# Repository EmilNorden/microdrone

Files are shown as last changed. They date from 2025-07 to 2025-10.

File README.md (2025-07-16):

# microdrone

## Controller dev kit

ESP32-S3-Wroom-1-n8r8\
Datasheet: https://www.espressif.com/sites/default/files/documentation/esp32-s3-wroom-1_wroom-1u_datasheet_en.pdf \
Hardware ref: https://docs.espressif.com/projects/esp-dev-kits/en/latest/esp32s3/esp32-s3-devkitc-1/user_guide_v1.1.html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 \
Power: 3.0-3.6V\
Rust dev on ESP32: https://docs.espressif.com/projects/rust/book/

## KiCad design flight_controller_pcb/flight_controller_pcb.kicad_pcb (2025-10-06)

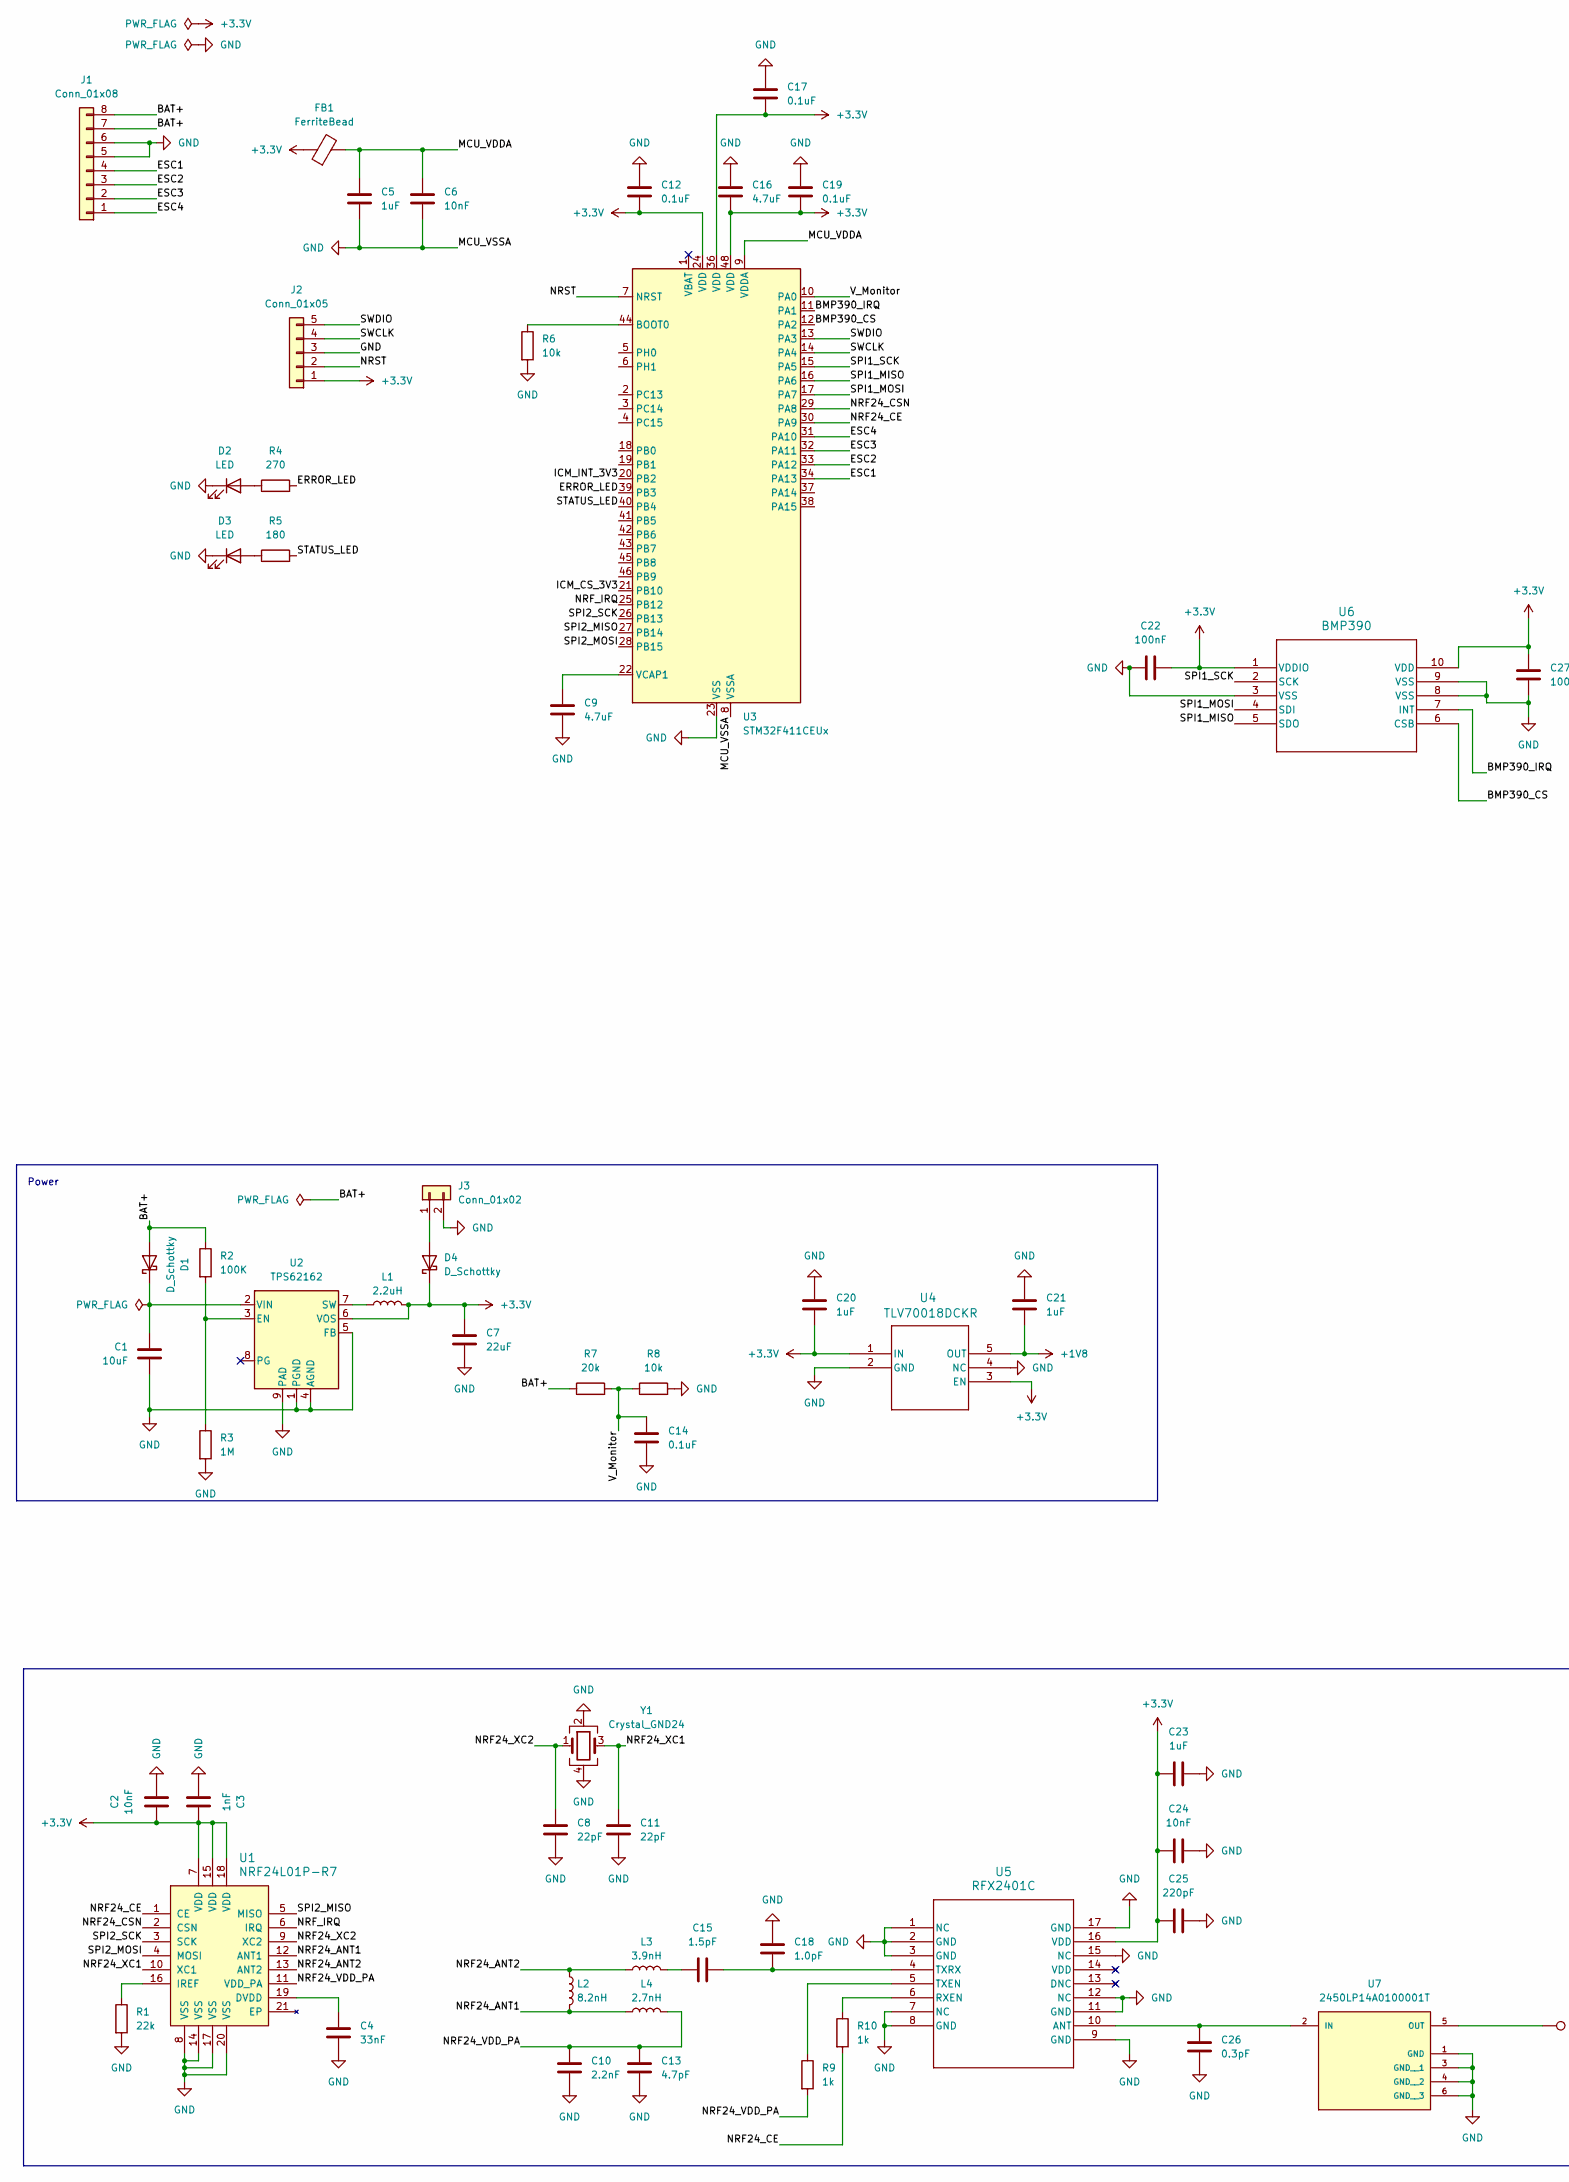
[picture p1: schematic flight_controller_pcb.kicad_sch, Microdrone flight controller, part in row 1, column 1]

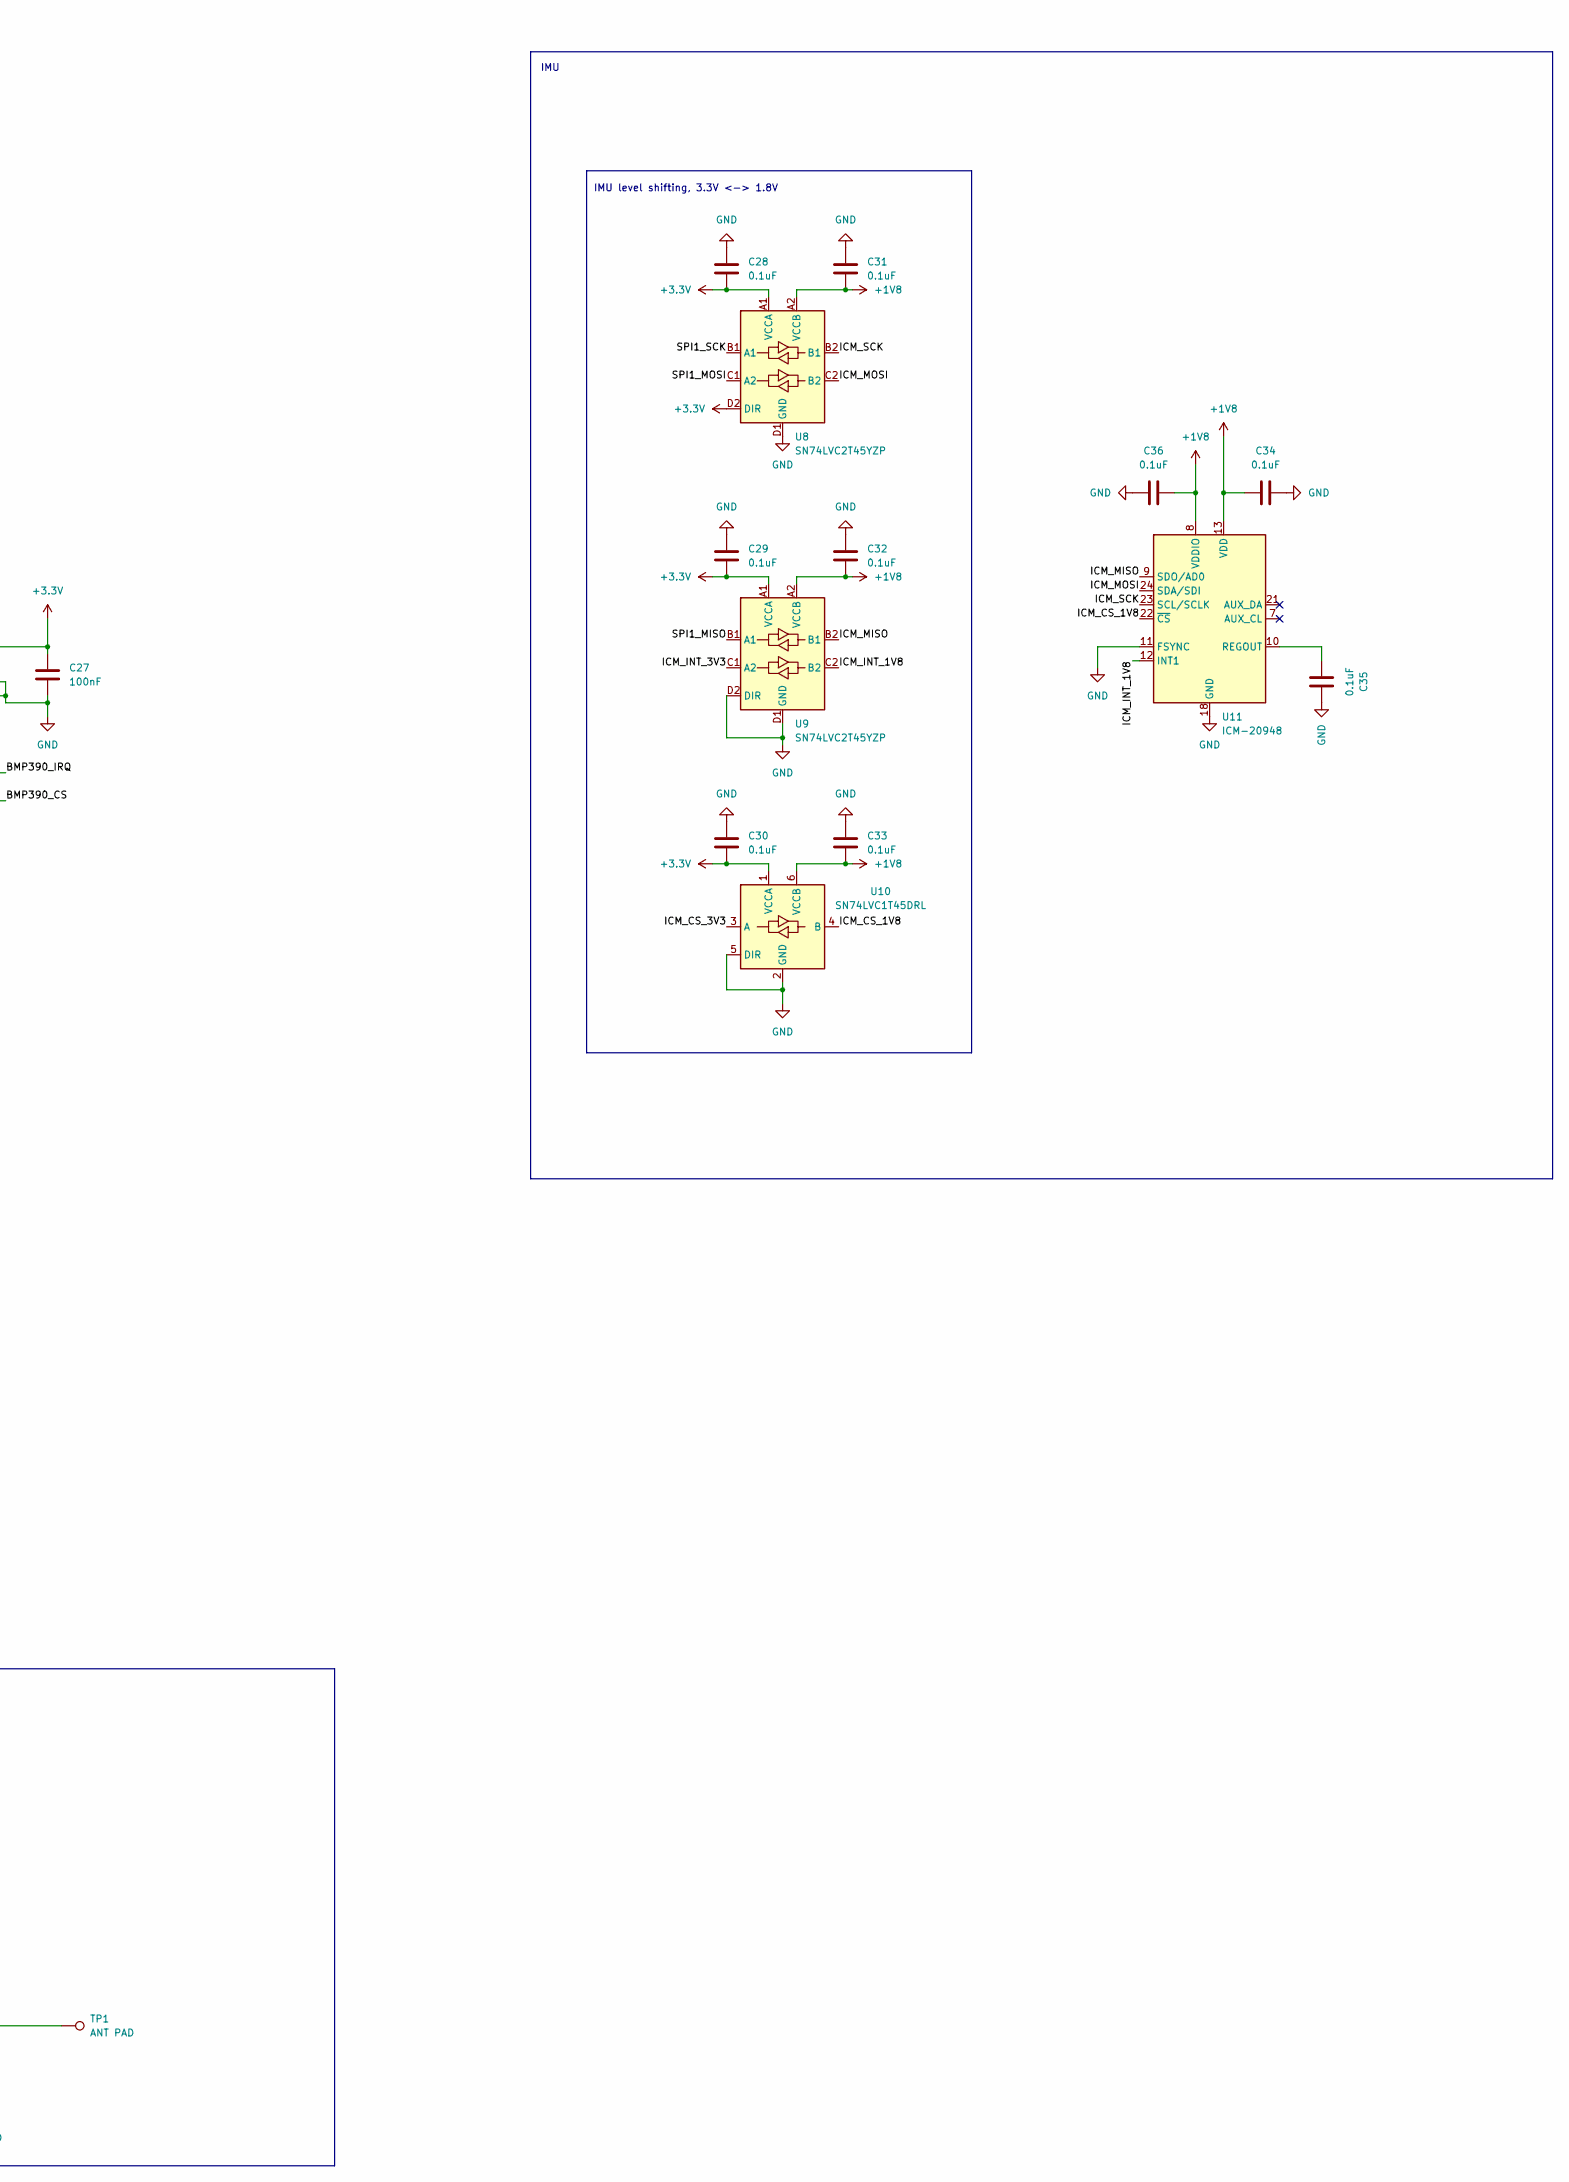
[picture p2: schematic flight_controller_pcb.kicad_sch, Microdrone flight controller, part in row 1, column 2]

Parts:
C1: 10uF; C_0603_1608Metric
C2, C6: 10nF; C_0402_1005Metric
C3: 1nF; C_0402_1005Metric
C4: 33nF; C_0402_1005Metric
C5, C20, C21, C23: 1uF; C_0402_1005Metric
C7: 22uF; C_0805_2012Metric
C8, C11: 22pF; C_0402_1005Metric
C9: 4.7uF; C_0603_1608Metric
C10: 2.2nF; C_0402_1005Metric
C12, C14, C17, C19, C28, C29, C30, C31, C32, C33: 0.1uF; C_0402_1005Metric
C13: 4.7pF; C_0402_1005Metric
C15: 1.5pF; C_0402_1005Metric
C16: 4.7uF; C_0603_1608Metric; LCSC C107368
C18: 1.0pF; C_0402_1005Metric
C22, C27: 100nF; C_0402_1005Metric
C24: 10nF; C_0603_1608Metric
C25: 220pF; C_0402_1005Metric
C26: 0.3pF; C_0201_0603Metric
C34, C35, C36: 0.1uF; C_0402_1005Metric; LCSC C1525
D1: D_Schottky; D_SOD-323
D2, D3: LED; LED_0402_1005Metric
D4: D_Schottky; Diode_SMD_SOD-723
FB1: FerriteBead; L_0603_1608Metric; LCSC C1002
J1: Conn_01x08; JST_SH_ZX-SH1.0-8PWT; LCSC C7430450
J2: Conn_01x05; PinHeader_1x05_P2.54mm_Horizontal
J3: Conn_01x02; PinHeader_1x02_P2.54mm_Horizontal
L1: 2.2uH; Inductor_Coilcraft_XFL3012-222MEC
L2: 8.2nH; L_0201_0603Metric
L3: 3.9nH; L_0201_0603Metric
L4: 2.7nH; L_0201_0603Metric
R1: 22k; R_0402_1005Metric
R2: 100K; R_0402_1005Metric
R3: 1M; R_0402_1005Metric
R4: 270; R_0402_1005Metric
R5: 180; R_0402_1005Metric
R6, R8: 10k; R_0402_1005Metric
R7: 20k; R_0402_1005Metric
R9, R10: 1k; R_0402_1005Metric
TP1: ANT PAD; TestPoint_Pad_3.0x3.0mm
U1: NRF24L01P-R7; QFN-20-1EP_4x4mm_RevA; MPN NRF24L01P-R7; Digi-Key_PN 1490-1033-1-ND
U2: TPS62162; WSON-8-1EP_2x2mm_P0.5mm_EP0.9x1.6mm_ThermalVias
U3: STM32F411CEUx; QFN-48-1EP_7x7mm_P0.5mm_EP5.6x5.6mm
U4: TLV70018DCKR; DCK5
U5: RFX2401C; RFX2401C_SKY
U6: BMP390; 10LGA_2X2X0p75_BOS
U7: 2450LP14A0100001T; ICCAF50P160X80X70-6N; PARTREV 06/23/03
U8, U9: SN74LVC2T45YZP; Texas_DSBGA-8_0.9x1.9mm_Layout2x4_P0.5mm
U10: SN74LVC1T45DRL; SOT-563
U11: ICM-20948; InvenSense_QFN-24_3x3mm_P0.4mm
Y1: Crystal_GND24; Crystal_SMD_3225-4Pin_3.2x2.5mm

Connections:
+1V8: C21.2, C31.2, C32.2, C33.2, C34.1, C36.2, U4.5 (OUT), U8.A2 (VCCB), U9.A2 (VCCB), U10.6 (VCCB), U11.8 (VDDIO), U11.13 (VDD)
+3.3V: C2.1, C3.1, C7.1, C12.1, C16.1, C17.1, C19.1, C20.2, C22.2, C23.1, C24.1, C25.1, C27.1, C28.2, C29.2, C30.2, D4.1 (K), FB1.1, J2.1, L1.2, U1.7 (VDD), U1.15 (VDD), U1.18 (VDD), U2.6 (VOS), U3.24 (VDD), U3.36 (VDD), U3.48 (VDD), U4.1 (IN), U4.3 (EN), U5.16 (VDD), U6.1 (VDDIO), U6.10 (VDD), U8.A1 (VCCA), U8.D2 (DIR), U9.A1 (VCCA), U10.1 (VCCA)
/BAT+: D1.2 (A), J1.7, J1.8, R2.1, R7.1
/BMP390_CS: U3.12 (PA2), U6.6 (CSB)
/BMP390_IRQ: U3.11 (PA1), U6.7 (INT)
/ERROR_LED: R4.2, U3.39 (PB3)
/ESC1: J1.4, U3.34 (PA13)
/ESC2: J1.3, U3.33 (PA12)
/ESC3: J1.2, U3.32 (PA11)
/ESC4: J1.1, U3.31 (PA10)
/ICM_CS_1V8: U10.4 (B), U11.22 (~CS)
/ICM_CS_3V3: U3.21 (PB10), U10.3 (A)
/ICM_INT_1V8: U9.C2 (B2), U11.12 (INT1)
/ICM_INT_3V3: U3.20 (PB2), U9.C1 (A2)
/ICM_MISO: U9.B2 (B1), U11.9 (SDO/AD0)
/ICM_MOSI: U8.C2 (B2), U11.24 (SDA/SDI)
/ICM_SCK: U8.B2 (B1), U11.23 (SCL/SCLK)
/MCU_VDDA: C5.1, C6.1, FB1.2, U3.9 (VDDA)
/NRF24_ANT1: L2.2, L4.1, U1.12 (ANT1)
/NRF24_ANT2: L2.1, L3.1, U1.13 (ANT2)
/NRF24_CE: R10.2, U1.1 (CE), U3.30 (PA9)
/NRF24_CSN: U1.2 (CSN), U3.29 (PA8)
/NRF24_VDD_PA: C10.1, C13.1, L4.2, R9.2, U1.11 (VDD_PA)
/NRF24_XC1: C11.1, U1.10 (XC1), Y1.3
/NRF24_XC2: C8.1, U1.9 (XC2), Y1.1
/NRF_IRQ: U1.6 (IRQ), U3.25 (PB12)
/NRST: J2.2, U3.7 (NRST)
/SPI1_MISO: U3.16 (PA6), U6.5 (SDO), U9.B1 (A1)
/SPI1_MOSI: U3.17 (PA7), U6.4 (SDI), U8.C1 (A2)
/SPI1_SCK: U3.15 (PA5), U6.2 (SCK), U8.B1 (A1)
/SPI2_MISO: U1.5 (MISO), U3.27 (PB14)
/SPI2_MOSI: U1.4 (MOSI), U3.28 (PB15)
/SPI2_SCK: U1.3 (SCK), U3.26 (PB13)
/STATUS_LED: R5.2, U3.40 (PB4)
/SWCLK: J2.4, U3.14 (PA4)
/SWDIO: J2.5, U3.13 (PA3)
/V_Monitor: C14.2, R7.2, R8.1, U3.10 (PA0)
GND: C1.2, C2.2, C3.2, C4.1, C5.2, C6.2, C7.2, C8.2, C9.1, C10.2, C11.2, C12.2, C13.2, C14.1, C16.2, C17.2, C18.1, C19.2, C20.1, C21.1, C22.1, C23.2, C24.2, C25.2, C26.2, C27.2, C28.1, C29.1, C30.1, C31.1, C32.1, C33.1, C34.2, C35.2, C36.1, D2.1 (K), D3.1 (K), J1.5, J1.6, J2.3, J3.2, R1.2, R3.2, R6.2, R8.2, U1.8 (VSS), U1.14 (VSS), U1.17 (VSS), U1.20 (VSS), U2.1 (PGND), U2.4 (AGND), U2.5 (FB), U2.9 (PAD), U3.8 (VSSA), U3.23 (VSS), U3.35 (VSS), U3.47 (VSS), U3.49 (VSS), U4.2 (GND), U4.4 (NC), U5.1 (NC), U5.2 (GND), U5.3 (GND), U5.7 (NC), U5.8 (GND), U5.9 (GND), U5.11 (GND), U5.12 (NC), U5.15 (NC), U5.17 (GND), U6.3 (VSS), U6.8 (VSS), U6.9 (VSS), U7.1 (GND), U7.3 (GND__1), U7.4 (GND__2), U7.6 (GND__3), U8.D1 (GND), U9.D1 (GND), U9.D2 (DIR), U10.2 (GND), U10.5 (DIR), U11.11 (FSYNC), U11.18 (GND), U11.20 (GND), Y1.2, Y1.4
unnamed: C15.1, L3.2
unnamed: C1.1, D1.1 (K), U2.2 (VIN)
unnamed: D2.2 (A), R4.1
unnamed: D3.2 (A), R5.1
unnamed: D4.2 (A), J3.1
unnamed: C4.2, U1.19 (DVDD)
unnamed: R1.1, U1.16 (IREF)
unnamed: R2.2, R3.1, U2.3 (EN)
unnamed: L1.1, U2.7 (SW)
unnamed: R6.1, U3.44 (BOOT0)
unnamed: C9.2, U3.22 (VCAP1)
unnamed: C26.1, U5.10 (ANT), U7.2 (IN)
unnamed: R10.1, U5.6 (RXEN)
unnamed: R9.1, U5.5 (TXEN)
unnamed: C15.2, C18.2, U5.4 (TXRX)
unnamed: TP1.1, U7.5 (OUT)
unnamed: C35.1, U11.10 (REGOUT)

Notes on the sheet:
IMU
IMU level shifting, 3.3V <-> 1.8V
Power

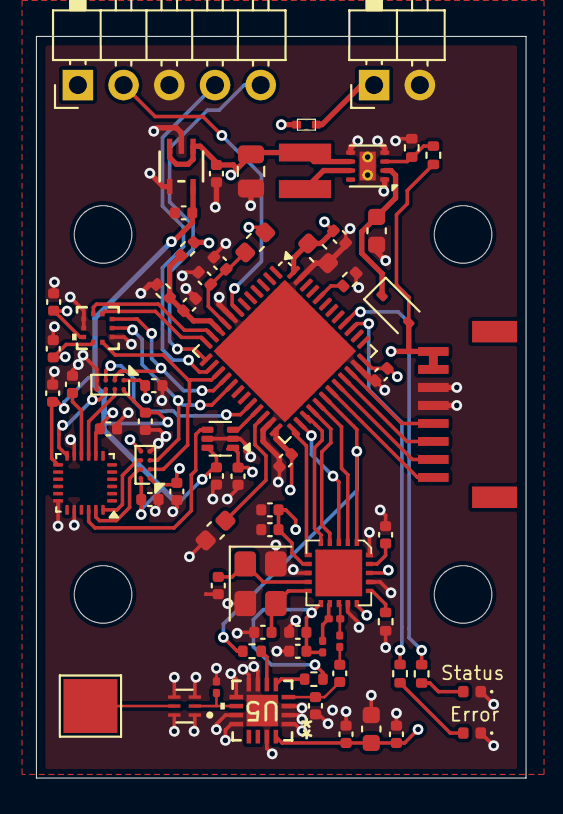
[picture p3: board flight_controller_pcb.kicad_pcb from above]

Board: 4 copper layers, 27.2 x 41.2 mm, 71 parts (0 on the bottom side), 55 nets.

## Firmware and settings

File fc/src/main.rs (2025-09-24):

#![no_std]
#![no_main]
mod bms;
mod env;
mod radio;
mod signal;

use crate::signal::{
    altitude_signal, drone_battery_level_signal, drone_battery_status_signal, new_drone_battery_level_signal_emitter,
    new_drone_battery_status_signal_emitter, BatteryStatus,
};
use defmt::*;
use embassy_embedded_hal::shared_bus::asynch::spi::SpiDevice;
use embassy_executor::Spawner;
use embassy_futures::select::{select, Either};
use embassy_stm32::adc::{Adc, AdcChannel, VREF_CALIB_MV};
use embassy_stm32::exti::ExtiInput;
use embassy_stm32::gpio::{Level, Output, Pull, Speed};
use embassy_stm32::mode::Async;
use embassy_stm32::peripherals::ADC1;
use embassy_stm32::spi::{Config, Spi};
use embassy_stm32::time::Hertz;
use embassy_sync::blocking_mutex::raw::NoopRawMutex;
use embassy_sync::mutex::Mutex;
use embassy_time::{Duration, Timer};
use fc_common::SignalBase;
use static_cell::StaticCell;
use {defmt_rtt as _, panic_probe as _};

static SPI_BUS: StaticCell<Mutex<NoopRawMutex, Spi<Async>>> = StaticCell::new();

fn read_calibrated_vdda(adc: &mut Adc<ADC1>) -> u32 {
    let mut vref = adc.enable_vrefint();

    let vref_raw = adc.blocking_read(&mut vref);

    let vref_cal = unsafe { core::ptr::read_volatile(0x1FFF_7A2A as *const u16) };

    VREF_CALIB_MV * (vref_cal as u32) / (vref_raw as u32)
}

async fn timeout<A: Future>(duration: Duration, awaitable: A) -> Option<A::Output> {
    match select(Timer::after(duration), awaitable).await {
        Either::First(_) => None,
        Either::Second(x) => Some(x),
    }
}

async fn battery_power_on_self_test() {
    let mut battery_status = drone_battery_status_signal();
    let battery_status = timeout(Duration::from_secs(1), battery_status.next_value()).await;

    match battery_status {
        None => defmt::panic!("Battery status timeout"),
        Some(BatteryStatus::Critical) => defmt::panic!("Battery level critical."),
        Some(_) => {}
    };
}

#[embassy_executor::main]
async fn main(spawner: Spawner) {
    let p = embassy_stm32::init(Default::default());
    info!("Flight controller starting.");

    // Start-up BMS (Battery Management Subsystem) first
    spawner
        .spawn(bms::run(
            p.PA0.degrade_adc(),
            Adc::new(p.ADC1),
            new_drone_battery_level_signal_emitter(),
            new_drone_battery_status_signal_emitter(),
        ))
        .unwrap();

    // Halt start-up if battery level is critical
    battery_power_on_self_test().await;

    // Setup SPI
    let mut spi_config = Config::default();
    spi_config.frequency = Hertz(1_000_000);
    let spi = Spi::new(
        p.SPI1, p.PA5, p.PA7, p.PA6, p.DMA2_CH3, p.DMA2_CH2, spi_config,
    );
    let spi_bus = Mutex::new(spi);
    let spi_bus = SPI_BUS.init(spi_bus);

    // NRF24L01+
    let radio_cs = Output::new(p.PB13, Level::High, Speed::Low);
    let radio_device = SpiDevice::new(spi_bus, radio_cs);

    let radio_ce = Output::new(p.PB12, Level::High, Speed::Low);
    let radio_irq = ExtiInput::new(p.PB1, p.EXTI1, Pull::Up);
    spawner
        .spawn(radio::run(
            radio_device,
            radio_ce,
            radio_irq,
            drone_battery_level_signal(),
            altitude_signal(),
        ))
        .unwrap();

    let bmp390_cs = Output::new(p.PB14, Level::High, Speed::Low);
    let bmp390_device = SpiDevice::new(spi_bus, bmp390_cs);
    let bmp390_irq = ExtiInput::new(p.PB6, p.EXTI6, Pull::Up);

    spawner.spawn(env::run(bmp390_device, bmp390_irq)).unwrap();
    /*
    let r = adc.blocking_read(&mut battery);

    let mut buf = [0u16; 32];

    // Enable DMA2 clock
    embassy_stm32::pac::RCC.ahb1enr().modify(|w| w.set_dma2en(true));

    // Disable stream
    embassy_stm32::pac::DMA2.st(0).cr().modify(|w| w.set_en(false));
    while embassy_stm32::pac::DMA2.st(0).cr().read().en() {}

    embassy_stm32::pac::DMA2.ifcr(0).write(|w| {
        w.set_tcif(0, true);
        w.set_htif(0, true);
        w.set_teif(0, true);
        w.set_dmeif(0, true);
        w.set_feif(0, true);
    });*/

    // Set up TIM3
    //embassy_stm32::pac::RCC.apb1enr().modify(|w| w.set_tim3en(true));
    /*
        let timer = embassy_stm32::timer::low_level::Timer::new(p.TIM3);
        timer.set_frequency(Hertz(400));
        // Set TRGO to trigger on update event. This has no API in the embassy low level driver, so I have to go through PAC.
        embassy_stm32::pac::TIM3.cr2().modify(|w| w.set_mms(Mms::UPDATE));
        timer.start();
    */

    info!("Flight controller started!");
    core::future::pending::<()>().await;
}

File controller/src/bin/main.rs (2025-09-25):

#![no_std]
#![no_main]
#![deny(
    clippy::mem_forget,
    reason = "mem::forget is generally not safe to do with esp_hal types, especially those \
    holding buffers for the duration of a data transfer."
)]

extern crate alloc;

use core::cell::RefCell;
use core::mem::ManuallyDrop;

use controller::signal::{
    battery_signal, controller_connected_signal, drone_altitude_signal, drone_battery_level_signal, input_signal,
    new_battery_signal_emitter, new_controller_connected_signal_emitter, new_drone_altitude_signal_emitter,
    new_drone_battery_level_signal_emitter, new_input_signal_emitter, new_radio_link_quality_signal_emitter,
    new_radio_signal_emitter, radio_link_quality_signal, radio_signal,
};
use controller::{gui, input, radio};
use embassy_embedded_hal::shared_bus::{asynch, blocking};
use embassy_executor::Spawner;
use embassy_sync::blocking_mutex::raw::NoopRawMutex;
use embassy_sync::blocking_mutex::NoopMutex;
use embassy_sync::mutex::Mutex;
use esp_hal::clock::CpuClock;
use esp_hal::gpio::{Input, InputConfig, Level, Output, OutputConfig, Pull};
use esp_hal::spi::master::{Config, Spi};
use esp_hal::spi::Mode;
use esp_hal::time::Rate;
use esp_hal::timer::systimer::SystemTimer;
use esp_hal::timer::timg::TimerGroup;
use esp_hal::{Async, Blocking};
use esp_wifi::EspWifiController;
use static_cell::StaticCell;

#[panic_handler]
fn panic(p: &core::panic::PanicInfo) -> ! {
    esp_println::println!("Panic occurred: {:?}", p);
    loop {}
}

// This creates a default app-descriptor required by the esp-idf bootloader.
// For more information see: <https://docs.espressif.com/projects/esp-idf/en/stable/esp32/api-reference/system/app_image_format.html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>
esp_bootloader_esp_idf::esp_app_desc!();

static SPI2_BUS: StaticCell<Mutex<NoopRawMutex, Spi<Async>>> = StaticCell::new();
//static SPI3_BUS: StaticCell<BlockingMutex<NoopRawMutex, Spi<Blocking>>> = StaticCell::new();
static SPI3_BUS: StaticCell<NoopMutex<RefCell<Spi<Blocking>>>> = StaticCell::new();

#[esp_hal_embassy::main]
async fn main(spawner: Spawner) {
    // generator version: 0.5.0
    esp_println::logger::init_logger_from_env();
    let config = esp_hal::Config::default().with_cpu_clock(CpuClock::max());
    let peripherals = esp_hal::init(config);

    esp_alloc::heap_allocator!(size: 64 * 1024);

    let timg0 = TimerGroup::new(peripherals.TIMG0);

    esp_println::println!("Init WIFI!");
    let wifi_init = esp_wifi::init(timg0.timer0, esp_hal::rng::Rng::new(peripherals.RNG))
        .expect("Failed to initialize WIFI/BLE controller");

    let systimer = SystemTimer::new(peripherals.SYSTIMER);
    esp_hal_embassy::init(systimer.alarm0);

    let local_wifi = ManuallyDrop::new(wifi_init);
    let local_wifi: &'static EspWifiController<'static> = unsafe { core::mem::transmute(&local_wifi) };
    //let local_wifi:  &'static EspWifiController<'static> = unsafe { &*(&*local_wifi as *const _) };

    // Initialize SPI2
    let spi2 = Spi::new(
        peripherals.SPI2,
        Config::default().with_frequency(Rate::from_mhz(4)).with_mode(Mode::_0),
    )
    .unwrap()
    .with_sck(peripherals.GPIO37)
    .with_mosi(peripherals.GPIO38)
    .with_miso(peripherals.GPIO39)
    .into_async();

    let spi2_bus = Mutex::new(spi2);
    let spi2_bus = SPI2_BUS.init(spi2_bus);

    // Initialize SPI3
    let spi3 = Spi::new(
        peripherals.SPI3,
        Config::default().with_frequency(Rate::from_mhz(4)).with_mode(Mode::_0),
    )
    .unwrap()
    .with_sck(peripherals.GPIO16)
    .with_mosi(peripherals.GPIO17)
    .with_miso(peripherals.GPIO18);

    let spi3_bus = SPI3_BUS.init(NoopMutex::new(RefCell::new(spi3)));

    let display_cs = Output::new(peripherals.GPIO36, Level::High, OutputConfig::default());
    let display_rst = Output::new(peripherals.GPIO19, Level::Low, OutputConfig::default());
    let display_dc = Output::new(peripherals.GPIO35, Level::Low, OutputConfig::default());
    let display_device = blocking::spi::SpiDevice::new(spi3_bus, display_cs);

    let radio_cs = Output::new(peripherals.GPIO14, Level::High, OutputConfig::default());
    let radio_ce = Output::new(peripherals.GPIO13, Level::Low, OutputConfig::default());
    let radio_device = asynch::spi::SpiDevice::new(spi2_bus, radio_cs);
    let radio_irq = Input::new(peripherals.GPIO12, InputConfig::default().with_pull(Pull::Up));

    /* Create signal emitters */
    let battery_emitter = new_battery_signal_emitter();
    let input_emitter = new_input_signal_emitter();
    let controller_emitter = new_controller_connected_signal_emitter();
    let radio_status_emitter = new_radio_signal_emitter();
    let drone_battery_emitter = new_drone_battery_level_signal_emitter();
    let drone_altitude_emitter = new_drone_altitude_signal_emitter();
    let radio_link_quality_emitter = new_radio_link_quality_signal_emitter();

    /* Start up sub-systems */
    spawner
        .spawn(input::run(
            local_wifi,
            peripherals.BT,
            battery_emitter,
            input_emitter,
            controller_emitter,
        ))
        .unwrap();
    spawner
        .spawn(gui::run(
            display_device,
            display_rst,
            display_dc,
            battery_signal(),
            radio_signal(),
            controller_connected_signal(),
            drone_battery_level_signal(),
            drone_altitude_signal(),
            radio_link_quality_signal(),
        ))
        .unwrap();
    spawner
        .spawn(radio::run(
            radio_device,
            radio_ce,
            radio_irq,
            input_signal(),
            radio_status_emitter,
            drone_altitude_emitter,
            drone_battery_emitter,
            radio_link_quality_emitter,
        ))
        .unwrap();

    core::future::pending::<()>().await;
}

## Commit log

2025-08-05 initial commit of FC pcb
    [flight_controller_pcb.kicad_pcb, flight_controller_pcb.kicad_sch]
2025-08-05 assigned several footprints in FC schema
    [flight_controller_pcb.kicad_sch]
2025-08-08 Started work to replace mpu-6500 with icm-20948
    [flight_controller_pcb.kicad_sch]
2025-08-11 tons of work on radio communication between controller and fc
    [flight_controller_pcb.kicad_sch]
2025-09-02 Adde interrupt line for bmp390
    [flight_controller_pcb.kicad_sch]
2025-09-12 Rewrote telemetry + added crude BMS subsystem
2025-09-15 ALOT of work on the PCB
    [flight_controller_pcb.kicad_pcb, flight_controller_pcb.kicad_sch]
2025-09-20 Display drone battery level on display
2025-09-25 pcb routing
2025-09-25 added datasheets for esp32 and stm32 mcu + technical reference for stm32
2025-09-25 split peripherals up into SPI2/SPI3 since ssd1351 driver does currently not support async
2025-09-26 moved interrupt await to *before* calculating link score
2025-10-01 alot of work on pcb layout
    [flight_controller_pcb.kicad_pcb, flight_controller_pcb.kicad_sch]
2025-10-03 routing work
    [flight_controller_pcb.kicad_pcb, flight_controller_pcb.kicad_sch]
2025-10-03 more routing
    [flight_controller_pcb.kicad_pcb]
2025-10-04 finished most of the traces
    [flight_controller_pcb.kicad_pcb]

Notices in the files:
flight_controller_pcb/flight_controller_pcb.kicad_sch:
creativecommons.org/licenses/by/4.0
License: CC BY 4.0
